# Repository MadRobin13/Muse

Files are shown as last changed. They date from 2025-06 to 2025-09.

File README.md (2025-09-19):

# 🐭 Muse – A Wearable Motion-Controlled Mouse for Disabled Creators


**[CLICK HERE FOR A VIDEO!!!](https://youtu.be/gZj0zO0jsb4?si=74KSr6B1YZtLEv0d)**

## ✨ What is Muse?

**Muse** is an open-source, wearable mouse created **for disabled creators**. It empowers users to access the internet and express their creativity, no matter their mobility challenges. Muse is designed to be affordable, customizable, and adaptable — because assistive technology should serve people, but not at the expense of their comfort.

Specifically, it is a motion-controlled mouse that can be worn on the **head, arm, or hand** — tailored to suit each individual’s abilities. Using a gyroscope and accelerometer, it translates body motion into mouse movement, enabling hands-free navigation, communication, and creation.

## 🎯 Key Features

- 🧠 **Head, Arm,and Hand tracking** using the MPU-6050 6-axis gyroscope sensor  
- 📡 **Powered by an ESP32-Wrover** for flexibility and performance  
- 💡 **LCD and DIY Haptic Motor** for interface and feedback
- 🛠️ **3D-printed clamp shell, base, and elastic strap** for wearable comfort and stable structure
- 🧩 **Modular & open-source**: adaptable for various types of disabilities  
- 🔌 **USB-powered** (Currently uses USB-C to draw 5V for power)

## 🧰 Hardware Components

- [ESP32-Wrover](https://www.espressif.com/en/products/socs/esp32-wrover)
- [MPU-6050 Gyroscope + Accelerometer](https://invensense.tdk.com/products/motion-tracking/6-axis/mpu-6050/)
- LCD Display
- Haptic motor for tactile feedback (Uses the small DC motor found in a [Sg90 9g Micro Servo Motor](https://www.amazon.ca/Micro-Helicopter-Airplane-Remote-Control/dp/B072V529YD?th=1))
- [3 way mini toggle switch](https://www.aircraftspruce.ca/catalog/elpages/minitoggle.php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)
- 3D-printed clampshell case (All files found in the [CAD_designs](https://github.com/MadRobin13/Muse/tree/main/CAD_designs) folder)
- Wearable strap (made using a dollar store elastic strap)
- USB-C to USB-A cable for wired use

## 🔧 How It Works

1. **Wear Muse** on your head, arm, or hand (make sure you select the correct limb using the switch).
3. The **MPU-6050 sensor** detects orientation and movement.
4. The **ESP32** processes this input and sends mouse movement signals to a connected computer.
5. Tactile feedback is provided via the **haptic motor**.
6. Muse communicates via Bluetooth (the LCD will tell you if bluetooth is connected).

## 🚀 Getting Started

1. Flash the firmware to the ESP32-Wrover using [PlatformIO](https://platformio.org/) or the Arduino IDE.
2. Assemble the hardware by inserting the LCD and switch into the lid, putting the gyro and haptic motor (made by combining the 3D-printed weight with the DC motor) into the 3D-printed headband case, attaching the elastic to the headband case, wiring everything, and shoving the components in the big 3D-printed box, while also putting the 3D-printed lid on the headband case.
3. Plug the device into a computer via USB.
4. Strap it on, adjust the fit, and you're ready to go!

## 🤲 Why Muse?

Muse was created because too many assistive technologies are closed, overpriced, and inflexible. People with disabilities deserve tools that are **designed with them in mind**, not products marked up by corporations taking advantage of their needs and marketing rigid, one-size-fits-all solutions.

Muse is:

- **Customizable** to individual needs
- **Open-source** and modifiable
- **Affordable** and replicable
- **Designed to help**, not to profit

This project is about **freedom, accessibility, and dignity** — built with care and community in mind.

## 💬 Contributing

Contributions are welcome! Whether it’s software bugs, hardware tweaks, documentation, or CAD designs, your help can make Muse better for someone who needs it.

First:
```bash
# Clone the repo
git clone https://github.com/MadRobin13/Muse.git
```

Then:

  Flash [main.cpp](https://github.com/MadRobin13/Muse/blob/main/src/main.cpp) to the ESP-32

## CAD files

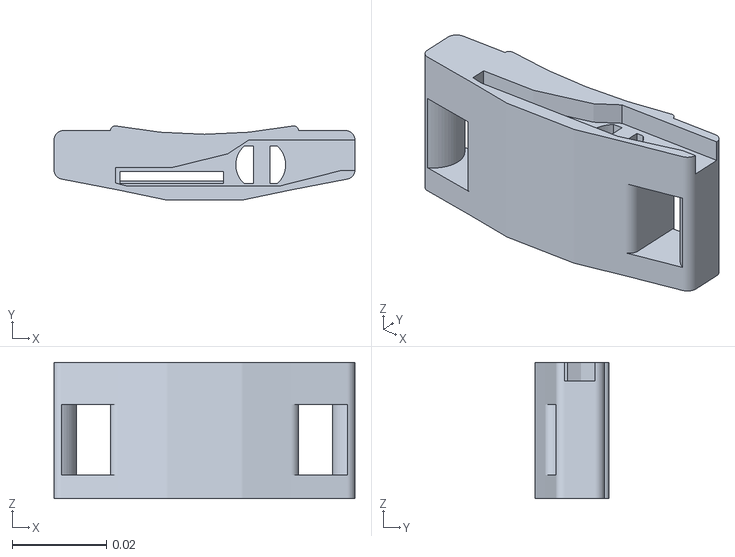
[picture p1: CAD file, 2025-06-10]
CAD_designs/headband/Last Version Main body.stl
0.064 x 0.0158 x 0.029

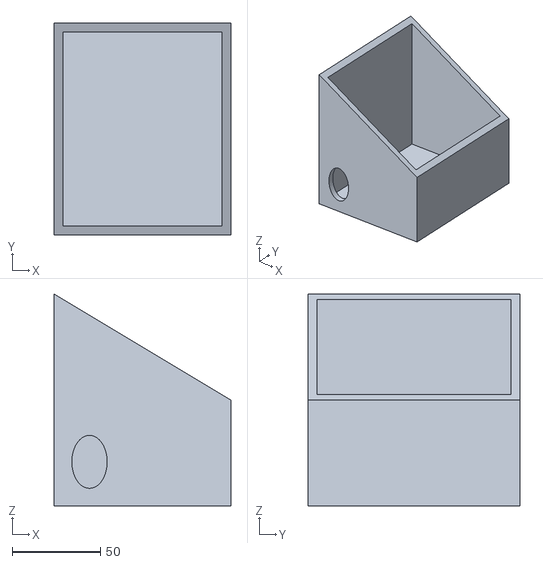
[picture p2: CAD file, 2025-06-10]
CAD_designs/case/Box v3.stl
100.0 x 120.0 x 120.0

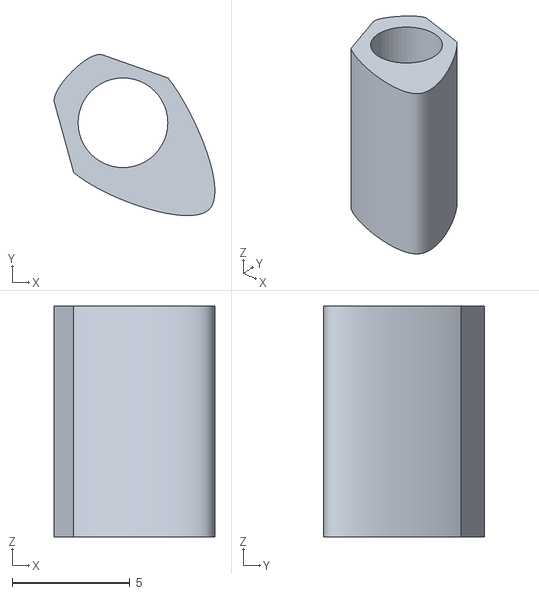
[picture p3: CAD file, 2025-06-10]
CAD_designs/haptic_motor/haptic_motor_attachment_v1.stl
6.82 x 6.84 x 9.80

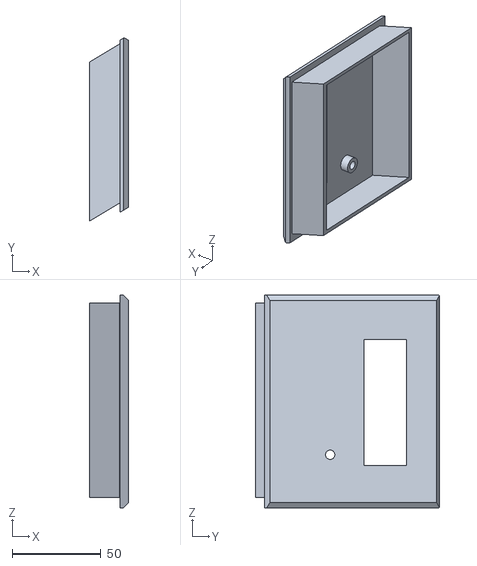
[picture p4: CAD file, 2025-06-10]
CAD_designs/case/Box lid v3.stl
22.1 x 103.4 x 120.0

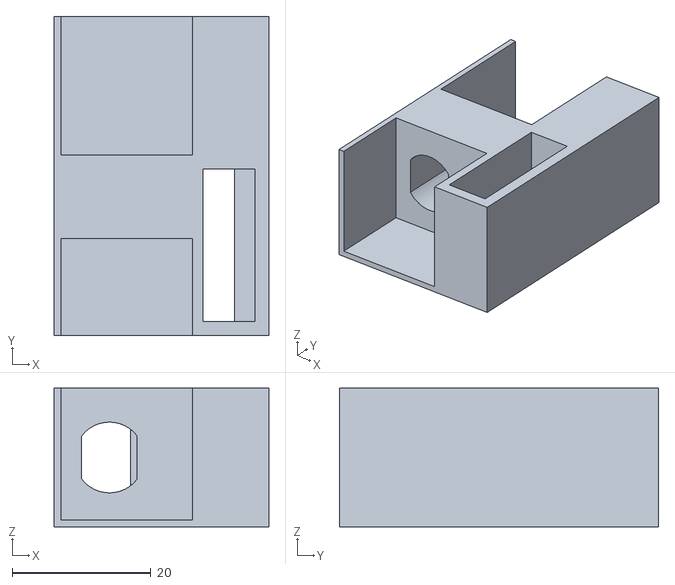
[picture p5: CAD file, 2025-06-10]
CAD_designs/headband/Head v4.stl
31.0 x 46.0 x 20.0

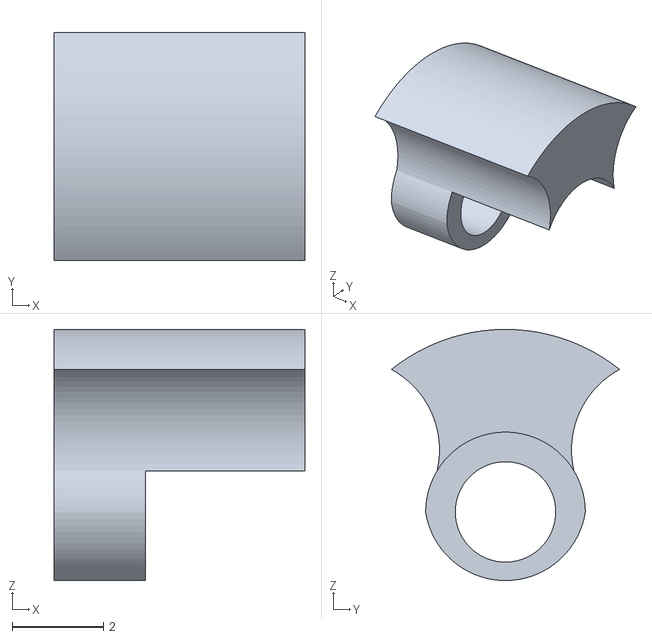
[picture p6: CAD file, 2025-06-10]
CAD_designs/haptic_motor/Hapic Motor weight v7.stl
5.50 x 5.00 x 5.50

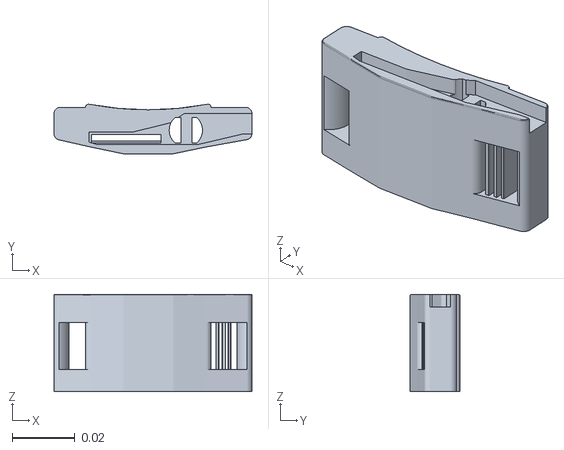
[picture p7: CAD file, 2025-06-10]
CAD_designs/headband/GyroBody(1).stl
0.063 x 0.0158 x 0.031

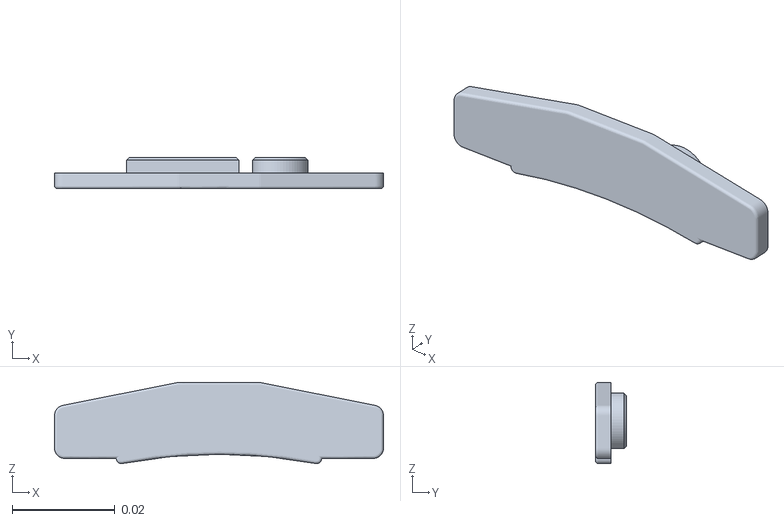
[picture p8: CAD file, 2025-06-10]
CAD_designs/headband/Lid(1).stl
0.064 x 0.006 x 0.0158

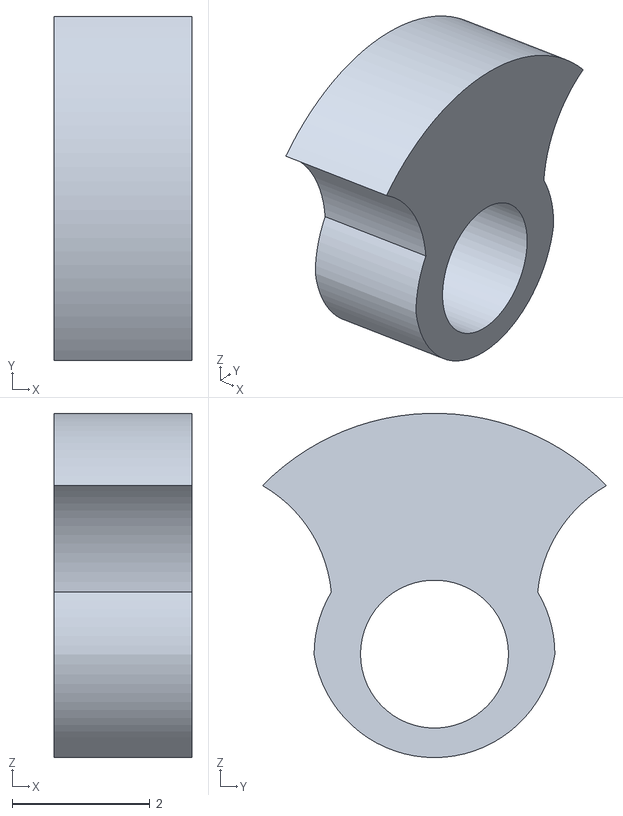
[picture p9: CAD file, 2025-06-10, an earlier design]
CAD_designs/haptic_motor/Hapic Motor weight v3.stl
2.00 x 5.00 x 5.00

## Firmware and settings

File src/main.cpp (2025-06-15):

#include <Wire.h>
#include <Adafruit_MPU6050.h>
#include <BleMouse.h>
#include <USB.h>
#include <esp_bt.h>
#include <esp_pm.h>
#include <esp_wifi.h>
#include <LiquidCrystal.h>
#include <string.h>

Adafruit_MPU6050 mpu;
const int rs = 26, en = 27, d4 = 5, d5 = 4, d6 = 0, d7 = 2;
LiquidCrystal lcd(rs, en, d4, d5, d6, d7);

BleMouse bleMouse("Muse");

float elapsedTime, currentTime, previousTime;
float roll, yaw = 0.0;

bool isConnected = false;
bool rightButtonPressed = false;
bool leftButtonPressed = false;
bool usingHead = true;
bool usingHand = false;
bool usingArm = false;

int16_t accX, accY, accZ;
int16_t gyroX, gyroY, gyroZ;

int16_t prevGyroX = 0;
int16_t prevGyroY = 0;
int16_t prevGyroZ = 0;

int16_t joystickFilter(int current, int previous, int coefficient)
{
	return (previous * (coefficient - 1) + current) / coefficient;
}

void keepMouseAlive()
{
	if (bleMouse.isConnected())
	{
		if (millis() % 1000 == 0)
		{
			bleMouse.move(1, 0);
		}
		else if (millis() % 1000 == 500)
		{
			bleMouse.move(-1, 0);
		}
	}
}

void setup()
{
	Serial.begin(115200);
	pinMode(15, OUTPUT);
	analogWrite(15, 0);

	esp_bt_controller_mem_release(ESP_BT_MODE_CLASSIC_BT);
	setCpuFrequencyMhz(240);

#ifdef CONFIG_PM_ENABLE
	esp_pm_config_t pm_config = {
		.max_freq_mhz = 240,
		.min_freq_mhz = 240,
		.light_sleep_enable = false};
	esp_pm_configure(&pm_config);
#endif

	esp_wifi_set_ps(WIFI_PS_NONE);
	bleMouse.begin();

	Wire.begin();
	if (!mpu.begin())
	{
		Serial.println("Failed to find MPU6050 chip");
		while (1)
			delay(10);
	}

	lcd.begin(16, 2);
	lcd.clear();
	previousTime = millis();

	pinMode(12, INPUT_PULLDOWN);
	pinMode(14, INPUT_PULLDOWN);
}

void loop()
{
	currentTime = millis();
	elapsedTime = (currentTime - previousTime) / 1000.0;
	previousTime = currentTime;

	sensors_event_t a, g, temp;
	mpu.getEvent(&a, &g, &temp);

	accX = (int16_t)(a.acceleration.x * 1000);
	accY = (int16_t)(a.acceleration.y * 1000);
	accZ = (int16_t)(a.acceleration.z * 1000);
	gyroX = (int16_t)(g.gyro.x * 1000);
	gyroY = (int16_t)(g.gyro.y * 1000);
	gyroZ = (int16_t)(g.gyro.z * 1000);

	roll = atan2(accY, sqrt(pow(accX, 2) + pow(accZ, 2))) * 180 / PI;
	yaw += gyroZ * elapsedTime * 180 / PI;
	yaw = fmod(yaw, 360.0);

	if (bleMouse.isConnected())
	{
		isConnected = true;

		if (usingHead)
		{
			gyroX = joystickFilter(gyroX, prevGyroX, 6);
			gyroY = joystickFilter(gyroY, prevGyroY, 2);
			prevGyroX = gyroX;
			prevGyroY = gyroY;

			float sensitivityX = 0.01;
			float sensitivityY = 0.01;
			int8_t moveX = -(int8_t)(gyroX * sensitivityX);
			int8_t moveY = (int8_t)(gyroY * sensitivityY);

			if (abs(moveX) > 1 || abs(moveY) > 1)
			{
				bleMouse.move(moveX, moveY);
			}

			if (accY > 5000 && !rightButtonPressed)
			{
				rightButtonPressed = true;
				bleMouse.press(MOUSE_RIGHT);
				analogWrite(15, 60);
			}
			else if (accY < 5000 && rightButtonPressed)
			{
				rightButtonPressed = false;
				bleMouse.release(MOUSE_RIGHT);
				analogWrite(15, 0);
			}

			if (accY < -5000 && !leftButtonPressed)
			{
				leftButtonPressed = true;
				bleMouse.press(MOUSE_LEFT);
				analogWrite(15, 60);
			}
			else if (accY > -5000 && leftButtonPressed)
			{
				leftButtonPressed = false;
				bleMouse.release(MOUSE_LEFT);
				analogWrite(15, 0);
			}
		}
		else if (usingHand)
		{
			gyroX = joystickFilter(gyroX, prevGyroX, 6);
			gyroY = joystickFilter(gyroY, prevGyroY, 2);
			prevGyroX = gyroX;
			prevGyroY = gyroY;

			float sensitivityX = 0.01;
			float sensitivityY = 0.01;
			int8_t moveX = -(int8_t)(gyroX * sensitivityX);
			int8_t moveY = -(int8_t)(gyroY * sensitivityY);

			if (abs(moveX) > 1 || abs(moveY) > 1)
			{
				bleMouse.move(moveX, moveY);
			}

			if (accY > 5000 && !rightButtonPressed)
			{
				rightButtonPressed = true;
				bleMouse.press(MOUSE_RIGHT);
				analogWrite(15, 60);
			}
			else if (accY < 5000 && rightButtonPressed)
			{
				rightButtonPressed = false;
				bleMouse.release(MOUSE_RIGHT);
				analogWrite(15, 0);
			}

			if (accY < -5000 && !leftButtonPressed)
			{
				leftButtonPressed = true;
				bleMouse.press(MOUSE_LEFT);
				analogWrite(15, 60);
			}
			else if (accY > -5000 && leftButtonPressed)
			{
				leftButtonPressed = false;
				bleMouse.release(MOUSE_LEFT);
				analogWrite(15, 0);
			}
		}
		else if (usingArm)
		{
			gyroZ = joystickFilter(gyroZ, prevGyroZ, 20);
			gyroY = joystickFilter(gyroY, prevGyroY, 5);
			prevGyroZ = gyroZ;
			prevGyroY = gyroY;

			float sensitivityX = 0.005;
			float sensitivityY = 0.022;
			int8_t moveX = -(int8_t)(gyroZ * sensitivityX);  // Use third axis for X
			int8_t moveY = -(int8_t)(gyroY * sensitivityY);

			if (abs(moveX) > 1 || abs(moveY) > 1)
			{
				bleMouse.move(moveX, moveY);
			}

			if (accY > 5000 && !rightButtonPressed)  // Use accX for click now
			{
				rightButtonPressed = true;
				bleMouse.press(MOUSE_RIGHT);
				analogWrite(15, 60);
			}
			else if (accY < 5000 && rightButtonPressed)
			{
				rightButtonPressed = false;
				bleMouse.release(MOUSE_RIGHT);
				analogWrite(15, 0);
			}

			if (accY < -5000 && !leftButtonPressed)
			{
				leftButtonPressed = true;
				bleMouse.press(MOUSE_LEFT);
				analogWrite(15, 60);
			}
			else if (accY > -5000 && leftButtonPressed)
			{
				leftButtonPressed = false;
				bleMouse.release(MOUSE_LEFT);
				analogWrite(15, 0);
			}
		}

		keepMouseAlive();
	}
	else
	{
		isConnected = false;
		analogWrite(15, 0);
	}

	// LCD Output

	if (millis() - previousTime > 1000)
	{
		lcd.clear();
		previousTime = millis();
	}

	lcd.setCursor(0, 0);
	lcd.print("BT: ");
	lcd.print(isConnected ? "Connected " : "Disconnected");

	lcd.setCursor(0, 1);
	lcd.print("Type: ");

	if (digitalRead(12) == HIGH && digitalRead(14) == LOW)
	{
		lcd.print("Head   ");
		usingHead = true;
		usingHand = false;
		usingArm = false;
	}
	else if (digitalRead(14) == HIGH && digitalRead(12) == LOW)
	{ 
		lcd.print("Hand  ");
		usingHead = false;
		usingHand = true;
		usingArm = false;
	}
	else if (digitalRead(12) == LOW && digitalRead(14) == LOW)
	{
		lcd.print("Arm    ");
		usingHead = false;
		usingHand = false;
		usingArm = true;
	}
	else
	{
		lcd.print("Error  ");
	}
}

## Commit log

2025-06-01 added some basic gyro code which works with the MPU-6050. Now I need to add some mouse control. This took WAY too long to debug.
    [main.cpp]
2025-06-01 movement is working. I just need to calubrate Z and change the coeffcient on Y. And fix the bluetooth irregularity.
    [main.cpp]
2025-06-08 Mouse is working with headband now. Awaiting STL files from partner to commit.
2025-06-10 Added all 3D designs until now. Needed to keep VSCode open to simulate time taken for CADing the designs. Hopefully these will be the final designs.
    [Box lid v3.stl, Box v3.stl, GyroBody(1).stl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]
2025-06-15 changed the 3D designs folder name
    [Box lid v3.stl, Box v3.stl, GyroBody(1).stl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]
